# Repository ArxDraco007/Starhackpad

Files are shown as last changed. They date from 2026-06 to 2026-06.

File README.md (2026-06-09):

# Starhackpad

## Why did I do this project?
If you use a computer, tablet, or phone (I don't know what you are using otherwise). A macropad is one of the best add-ons you can have to increase your productivity. A macropad is a small, compact, secondary keypad with fully programmable keys. It allows you to execute complex keyboard shortcuts, automate repetitive tasks, or launch applications with a single press of a button. One press of a button can run the commands to curse at your friends when they are playing like they usually would.

NOW FOR SOME...
## PICTURES!!! 


starpad


BOM! - 
## Kit Items

| Item | Description | Quantity | Unit Price ($) | Total Price ($) | Link |
|---|---|---|---|---|---|
| SEEED Studios XIAO RP2040 | Microcontroller | 1 | 6.57 | 6.57 | https://robu.in/product/seeed-studio-xiao-rp2040-v1-0/ |
| Cherry MX Switches | Switches | 10 | 0.399 | 3.99 | https://meckeys.com/shop/accessories/keyboard-accessories/key-switches/cherry-mx-rgb-switch/ |
| Blank Cherry MX-Style Keycaps | Keycaps | 5 | 0.212 | 1.06 | https://meckeys.com/shop/accessories/keyboard-accessories/keycaps/blank-dsa-keycaps-1u/ |
| Alps EC-11 Rotary Encoder | Knob | 1 | 1.28 | 1.28 | https://roboticsdna.in/product/rotary-encoder-module-for-arduino-brick-sensor-development-round-audio-rotating-potentiometer-knob-cap-ec11/ |
| M3x16mm Screws | Case Screws | 1 | 2.99 | 2.99 | https://www.amazon.in/Immech-Socket-Stainless-Machine-Quantity/dp/B07XYRXMML |
| M3x5x4mm Heat-Set Inserts | Case Screw Inserts | 1 | 0.95 | 0.95 | https://robu.in/product/m3-x-4-mm-brass-heat-set-knurl-threaded-round-insert-nut-25-pcs/ |
**Final Price for Kit Items: $16.84**
Case Items
| Item | Description | Quantity | Unit Price ($) | Total Price ($) | Link |
| 3D-printed Case (Self-Provided) | Approx. 156g PLA | 1 | 0 | 0 | — |
| LionCircuits PCB for Hackpad | PCB (MOQ 5) | 5 | 1.80 | 9.00 | https://order.lioncircuits.com/projectdetails/212426/quotation |
Final Price for Case Items: $9
Grand Total
| Category | Cost ($) |
| Kit Items | 16.84 |
| Case Items | 9 |
| **Grand Total** | **25.60** |

Tutorial - https://hackpad.hackclub.com/

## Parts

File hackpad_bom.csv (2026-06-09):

KIT Items | Description | Quantity | Unit Price ($) | Total Price ($) | Link
SEEED Studios XIAO RP2040 | Microcontroller | 1 | 6.57 | 6.57 | https://robu.in/product/seeed-studio-xiao-rp2040-v1-0/
Cherry MX Switches | Switches | 10 | 0.399 | 3.99 (MOQ 10) | https://meckeys.com/shop/accessories/keyboard-accessories/key-switches/cherry-mx-rgb-switch/
Blank Cherry MX-Style Keycaps | Keycaps | 5 | 0.212 | 1.06 (MOQ 5) | https://meckeys.com/shop/accessories/keyboard-accessories/keycaps/blank-dsa-keycaps-1u/
Alps EC-11 Rotary Encoder | Knob | 1 | 1.28 | 1.28 | https://roboticsdna.in/product/rotary-encoder-module-for-arduino-brick-sensor-development-round-audio-rotating-potentiometer-knob-cap-ec11/
M3x16mm Screws | Case Screws | 1 | 2.99 | 2.99 | https://www.amazon.in/Immech-Socket-Stainless-Machine-Quantity/dp/B07XYRXMML
M3x5x4mm Heat-Set Inserts | Case Screw Inserts | 1 | 0.95 | 0.95 | https://robu.in/product/m3-x-4-mm-brass-heat-set-knurl-threaded-round-insert-nut-25-pcs/
FINAL PRICE FOR KIT ITEMS: | $16.84 | (COMES WITH THE KIT!!!)
CASE Items | Description | Quantity | Unit Price ($) | Total Price ($) | URL
3D-printed case (SELF-PROVIDED) | Approx. 156g of PLA | 1 | 1.76 | 1.76
LionCircuits | PCB for Hackpad | 5 | 9.00 | 9.00 (MOQ 5) | https://order.lioncircuits.com/projectdetails/212426/quotation
CASE ITEMS SUBTOTAL: | $10.76
FINAL PRICE FOR GRANT: | $16.84

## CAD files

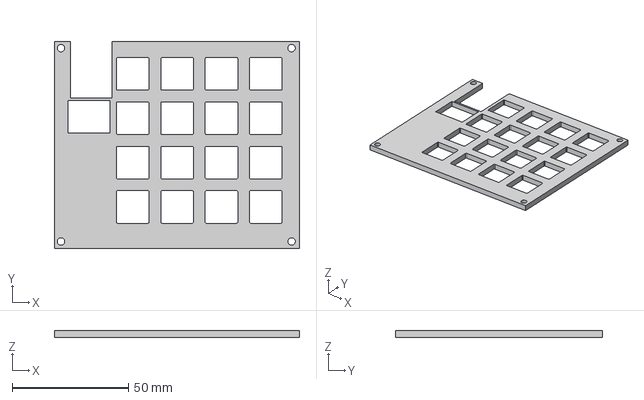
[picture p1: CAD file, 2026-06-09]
CAD/top.step
105.2 x 88.7 x 3.00 mm

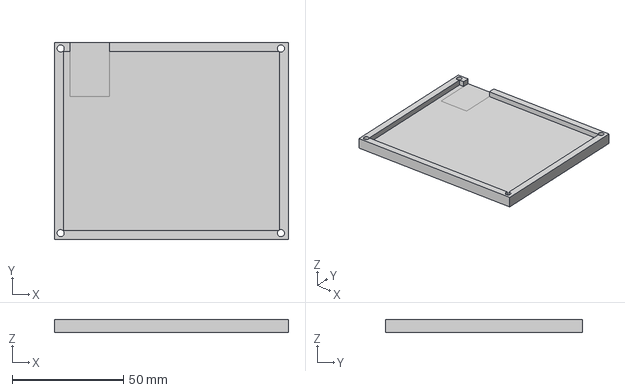
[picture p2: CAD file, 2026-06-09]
CAD/bottom.step
105.2 x 88.7 x 6.04 mm

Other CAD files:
CAD/assembly.f3z

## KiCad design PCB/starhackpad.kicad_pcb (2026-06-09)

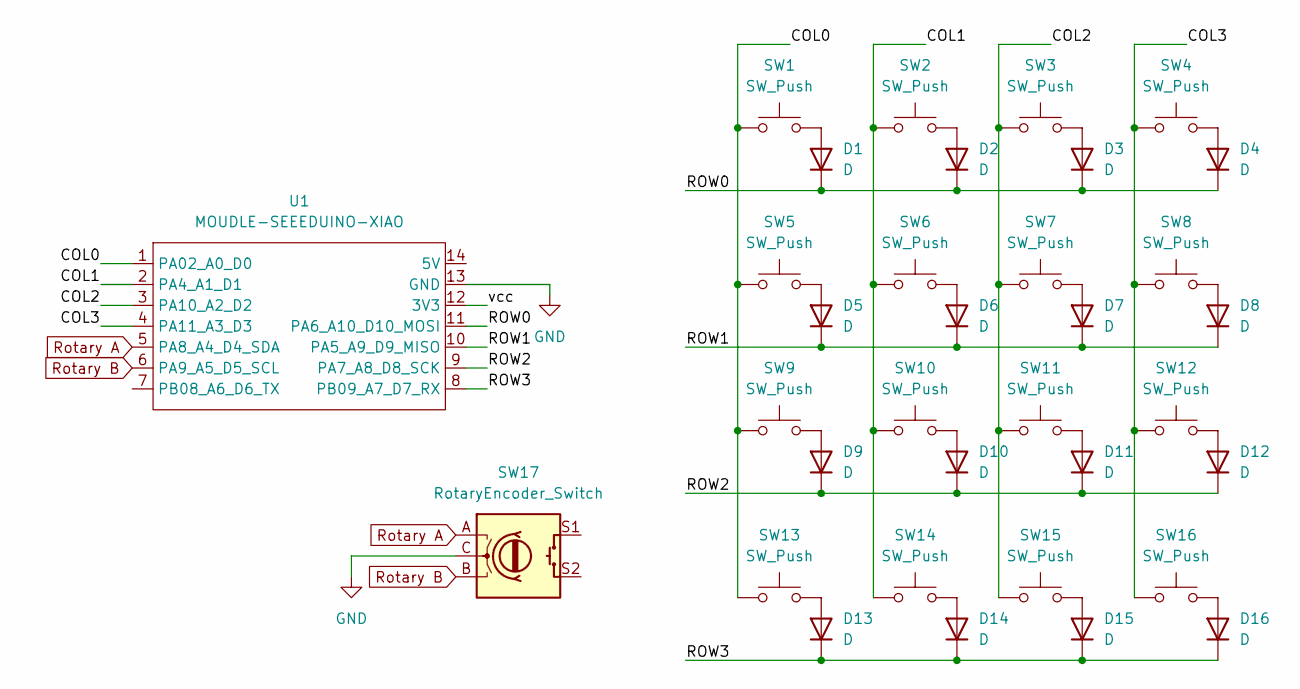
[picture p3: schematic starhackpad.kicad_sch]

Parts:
D1, D2, D3, D4, D5, D6, D7, D8, D9, D10, D11, D12, D13, D14, D15, D16: D; D_SOD-123
SW1, SW2, SW3, SW4, SW5, SW6, SW7, SW8, SW9, SW10, SW11, SW12, SW13, SW14, SW15, SW16: SW_Push; SW_Cherry_MX_1.00u_PCB
SW17: RotaryEncoder_Switch; RotaryEncoder_Alps_EC11E-Switch_Vertical_H20mm
U1: MOUDLE-SEEEDUINO-XIAO; XIAO-Generic-Hybrid-14P-2.54-21X17.8MM

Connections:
/COL0: SW1.1, SW5.1, SW9.1, SW13.1, U1.1 (PA02_A0_D0)
/COL1: SW2.1, SW6.1, SW10.1, SW14.1, U1.2 (PA4_A1_D1)
/COL2: SW3.1, SW7.1, SW11.1, SW15.1, U1.3 (PA10_A2_D2)
/COL3: SW4.1, SW8.1, SW12.1, SW16.1, U1.4 (PA11_A3_D3)
/ROW0: D1.1 (K), D2.1 (K), D3.1 (K), D4.1 (K), U1.11 (PA6_A10_D10_MOSI)
/ROW1: D5.1 (K), D6.1 (K), D7.1 (K), D8.1 (K), U1.10 (PA5_A9_D9_MISO)
/ROW2: D9.1 (K), D10.1 (K), D11.1 (K), D12.1 (K), U1.9 (PA7_A8_D8_SCK)
/ROW3: D13.1 (K), D14.1 (K), D15.1 (K), D16.1 (K), U1.8 (PB09_A7_D7_RX)
/vcc: U1.12 (3V3)
GND: SW17.C, U1.13 (GND)
unnamed: D1.2 (A), SW1.2
unnamed: D2.2 (A), SW2.2
unnamed: D3.2 (A), SW3.2
unnamed: D4.2 (A), SW4.2
unnamed: D5.2 (A), SW5.2
unnamed: D6.2 (A), SW6.2
unnamed: D7.2 (A), SW7.2
unnamed: D8.2 (A), SW8.2
unnamed: D9.2 (A), SW9.2
unnamed: D10.2 (A), SW10.2
unnamed: D11.2 (A), SW11.2
unnamed: D12.2 (A), SW12.2
unnamed: D13.2 (A), SW13.2
unnamed: D14.2 (A), SW14.2
unnamed: D15.2 (A), SW15.2
unnamed: D16.2 (A), SW16.2
Rotary A: SW17.A, U1.5 (PA8_A4_D4_SDA)
Rotary B: SW17.B, U1.6 (PA9_A5_D5_SCL)

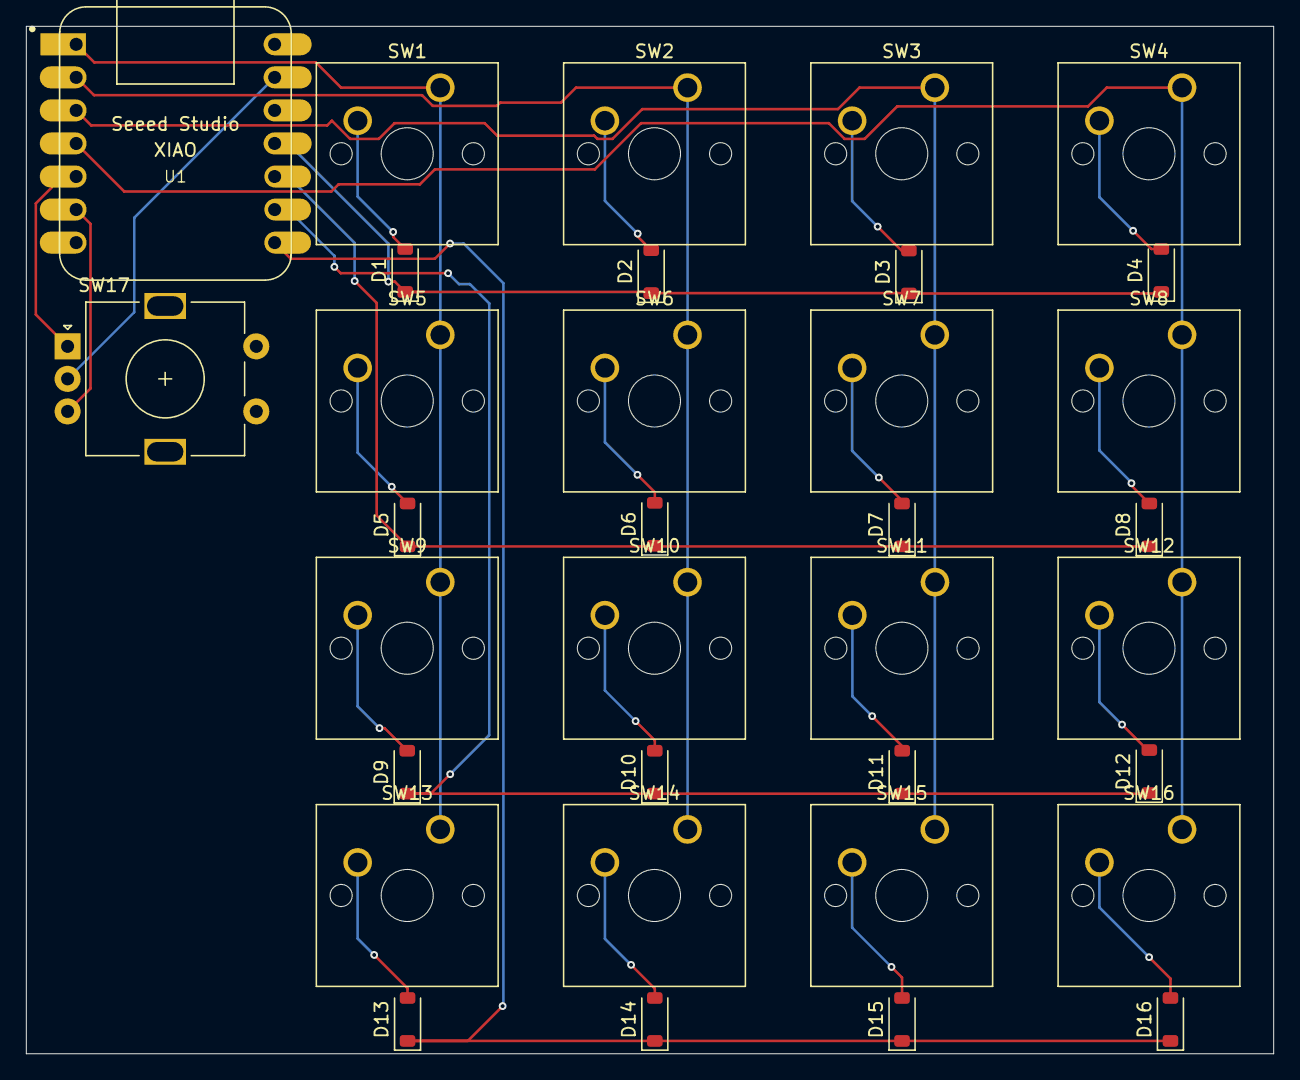
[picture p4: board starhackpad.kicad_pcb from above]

Board: 2 copper layers, 95.8 x 78.9 mm, 34 parts (0 on the bottom side), 27 nets.

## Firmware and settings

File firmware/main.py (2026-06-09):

import board
from kmk.kmk_keyboard import KMKKeyboard
from kmk.keys import KC
from kmk.scanners import DiodeOrientation
from kmk.modules.encoder import EncoderHandler

keyboard = KMKKeyboard()
keyboard.col_pins = (board.D0, board.D1, board.D2, board.D3)
keyboard.row_pins = (board.D10, board.D9, board.D8, board.D7)
keyboard.diode_orientation = DiodeOrientation.COL2ROW
encoder_handler = EncoderHandler()
keyboard.modules.append(encoder_handler)
keyboard.keymap = [
    [
        KC.NUM_1, KC.NUM_2, KC.NUM_3, KC.NUM_4,
        KC.NUM_5, KC.NUM_6, KC.NUM_7, KC.NUM_8,
        KC.NUM_9, KC.NUM_0, KC.BSPC,  KC.ENTER,
        KC.ESC,   KC.TAB,   KC.SPACE, KC.NO, 
    ]
]
encoder_handler.map = [
    [(KC.VOLD, KC.VOLU, KC.NO)],
]

encoder_handler.pins = ((board.D4, board.D5, None),)

if __name__ == "__main__":
    keyboard.go()
